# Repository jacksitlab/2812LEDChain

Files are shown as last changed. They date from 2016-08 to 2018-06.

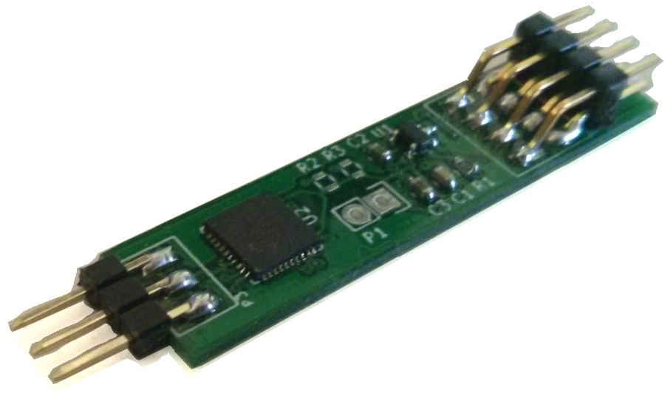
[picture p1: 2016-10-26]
platine.jpg

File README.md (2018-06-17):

## 2812LEDChain

This Project is based on a little piece of Hardware I build for accessing 2812LEDs via I2C-Bus(aka TWI). In my special case I use a Raspberry PI to control them.
The Clou: It is possible to wire them from board to board and control them seperately. So you can wire the seperated LEDChains from one to another.
The Controller works like a simple 32bit adressable I2C-EEPROM where you can write the RGB-Values.

## Why the extra board? There is already a lib for the raspi that can control 2812LEDs.

Yeah, thats right. But this lib is using the PWM-output Pin and many of my Projects are using this as it should be. That's why I want to put it on a place where I can control them with a seperate address.
 
## Folders

* pcb: all KiCAD files (Schematics and Layout files)
* firmware: all microcontroller files for CodeComposerStudio(from Texas Instruments)
* raspberry: all files to remote control the LEDChain from a Raspberry PI with python

## Installation / Usage

### Firmware installation

* File > Import > Code Composer Studio > CCS Projects
* Select Directory and Finish
* Debug with a programmer (a launchpad also works) with connected TEST and RESET Pin. Don't forget GND.

### For Raspberry PI with Python

* copy ws2812ledchain.py to your python project folder
* use it from a seperate file like this below.

```
	
	from ws2812ledchain import *

	chain=WS2812Chain(1)  //1 =>bus number(i2c-1 on raspi 2 and 3, i2c-0 on raspi 1)
	leds=chain.Add(0x44,256)  //0x44 => 7bit address of the chain element. 0x44 is the default. can be modified in firmware, 256 leds to handle
	leds.Test()
	leds.RingBuffer(500,0)  //shift forward every LED every 500ms 
	time.sleep(5)
	leds.RingBuffer(100,1)  //shift backward every LED every 100ms

```

### For Raspberry PI with Web-API

* install apache webserver

```

	pi@raspberrypi ~ $ sudo apt-get install apache2

```

* copy ws2812ledchain.py and api.py to /usr/lib/cgi-bin/
* change userrights for those files

```

	pi@raspberrypi ~ $ sudo chmod 0755 /usr/lib/cgi-bin/*.py

```

* add cgi support in your apache config file

```

	<Directory "/usr/lib/cgi-bin">
		AllowOverride None
		Options +ExecCGI -MultiViews +SymLinksIfOwnerMatch
		Order allow,deny
		Allow from all
	</Directory>

```

* maybe you have to enable cgi mod for apache

```

	sudo a2enmod cgi
	sudo /etc/init.d/apache2 restart
```

* make a simple get request with javascript from your page (here with jQuery)

```

	$.ajax({
		url:'cgi-bin/api.py?task='+task,
		success: function(r){
			console.log(r);
		}
    });

```

## TODO

* Set RGBChain Length via Command
* Change I2C-Address via Command
* Add more functions ...

## License

Beerware License.

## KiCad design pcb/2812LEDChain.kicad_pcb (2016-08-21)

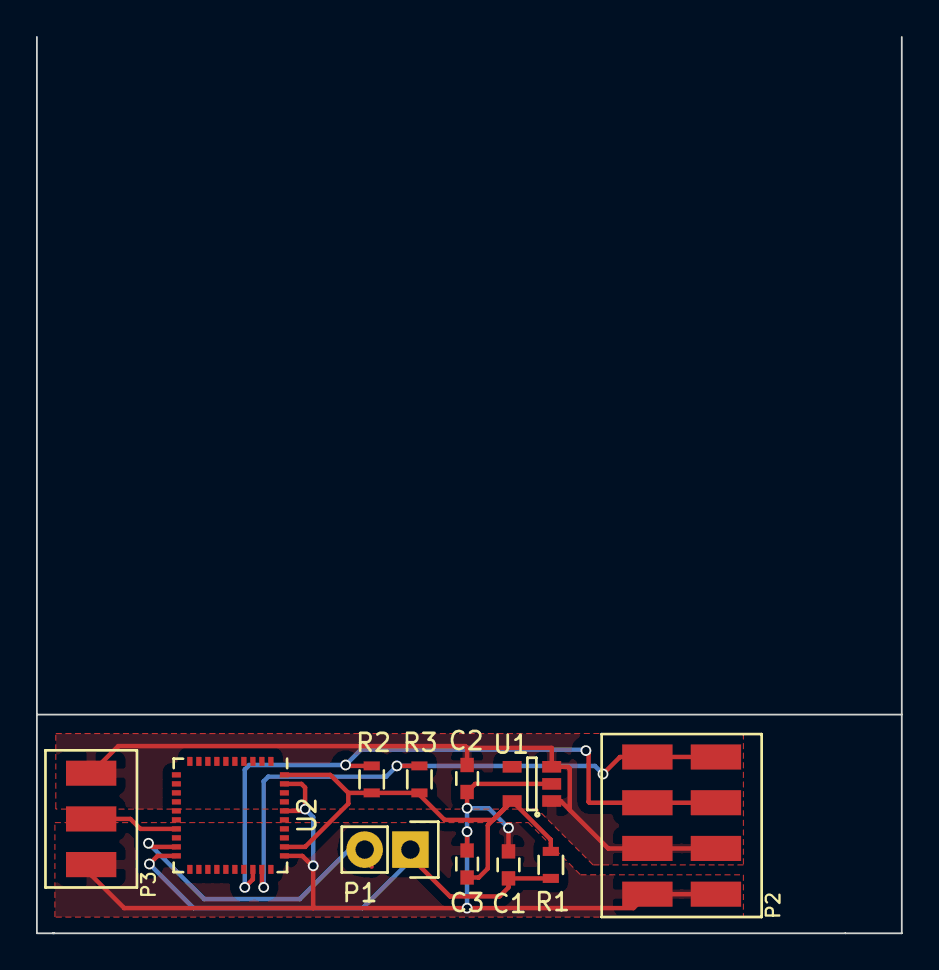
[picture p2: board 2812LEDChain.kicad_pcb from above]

Board: 2 copper layers, 48.1 x 49.8 mm, 11 parts (0 on the bottom side), 8 nets.

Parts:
C1: 1n; C_0603
C2, C3: 1u; C_0603
P1: CONN_01X02; Pin_Header_Straight_1x02
P2: CONN_02X04; PINHEAD1-8_SMD
P3: CONN_01X03; PINHEAD1-3_SMD
R1: 47k; R_0603
R2, R3: 10k; R_0603
U1: LD59015; SOT-23-5
U2: MSP430F5739; QFN-40-1EP_6x6mm_Pitch0.5mm

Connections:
+3V3: C3.1, R1.1, R2.1, R3.1, U1.5, U2.32, U2.40
+5V: C2.1, P2.5, P2.6, P3.1, U1.1, U1.3
/DO: P3.2, U2.17
/RST: C1.1, P1.1, R1.2, U2.20
/SCL: P2.1, P2.2, R3.2, U2.29
/SDA: P2.3, P2.4, R2.2, U2.28
/TEST: P1.2, U2.19
GND: C1.2, C2.2, C3.2, P2.7, P2.8, P3.3, U1.2, U2.31, U2.36, U2.39

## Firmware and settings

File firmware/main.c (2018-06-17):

/**
 * |==================================|
 * |                                  |
 * |           Memory 1               |
 * |          for RGB Values          |
 * |        Size: NUMLEDSMAX          |
 * |             (FRAM)               |
 * |==================================|
 *
 *
 * |==================================|
 * |                                  |
 * |           Memory 2               |
 * |        for DMA output            |
 * |  Size: 3* RGBMem + ResetOffset   |
 * |           (FRAM)                 |
 * |==================================|
 *
 *
 * |==================================|
 * |                                  |
 * |           Memory 3               |
 * |          for Config              |
 * |            (InfoB)               |
 * |==================================|
 *
 */



#include <msp430.h> 

#include "i2c.h"
#include "spi.h"
#include "constants.h"

#ifdef COMPILE_MINIMAL
#else
#include "demos.h"
#define PROGRAM_IDLE 0
#define PROGRAM_RECALCRGB 1
#define PROGRAM_OFFSET 2
#define PROGRAM_KITT 3
#define PROGRAM_RINGBUFFER 4
#define PROGRAM_FADEOUT 5
#define PROGRAM_FADEIN 6
#define PROGRAM_FADEOUT_LTR 7
#define PROGRAM_FADEIN_LTR 8
#define PROGRAM_FADEOUT_RTL 9
#define PROGRAM_FADEIN_RTL 10


unsigned int programMode=PROGRAM_IDLE;
static unsigned int timercounter=0;
#endif

void clock_init(void)
{
	 CSCTL0_H = 0xA5;
	  CSCTL1 |= DCORSEL + DCOFSEL0 + DCOFSEL1;   // Set max. DCO setting
	  CSCTL2 = SELA_3 + SELS_3 + SELM_3;        // set ACLK = MCLK = DCO
	  CSCTL3 = DIVA__32 + DIVS_0 + DIVM_0;        // set all dividers to 0

	  __delay_cycles(76563);
}
void i2c_onwritecomplete(unsigned char* ptr,unsigned int len)
{
	//spi_calculate(rgbmem,rgb_getnumleds());
	//spi_dma_write();
#ifdef COMPILE_MINIMAL
	spi_calculate(rgbmem,rgb_getlength());
    spi_dma_write();
#else
	programMode=PROGRAM_RECALCRGB;
#endif
}
unsigned int ringbufferreset=1000;
unsigned int fadetimerreset=1000;
unsigned int fadedirection_index=0;
void i2c_oncommand(unsigned int command,unsigned char* params)
{
#ifndef COMPILE_MINIMAL
	switch(command)
	{
		case COMMAND_OFFSET:
		{
			programMode=PROGRAM_OFFSET;
			parammem[0]=*params++;
			break;
		}
		case COMMAND_DEMO_KITT:
		{
			programMode=PROGRAM_KITT;
			timercounter=demo_getKITTCounterInit(rgb_getlength(),10);
			break;
		}
		case COMMAND_RINGBUFFER:
		{
			programMode=PROGRAM_RINGBUFFER;
			parammem[0]=*params++;
			parammem[1]=*params++;
			break;
		}
		case COMMAND_SETLENGTH:
		{
			unsigned int len=*params++;
			len<<=8;
			len+=*params;
			if(len>0 && len<NUMLEDSMAX)
				rgb_setlength(len);
			break;
		}
		case COMMAND_SETADDRESS:
		{
			break;
		}
		case COMMAND_SETFACTORS:
		{

			break;
		}
		case COMMAND_FADEOUT:
		case COMMAND_FADEIN:
		{
			parammem[0]=*params++;
			parammem[1]=*params++;
			programMode=command==COMMAND_FADEOUT?PROGRAM_FADEOUT:PROGRAM_FADEIN;
			break;
		}
		case COMMAND_FADEIN_LTR:
		case COMMAND_FADEOUT_LTR:
		{
			parammem[0]=*params++;
			parammem[1]=*params++;
			fadedirection_index=0;
			programMode=command==COMMAND_FADEOUT_LTR?PROGRAM_FADEOUT_LTR:PROGRAM_FADEIN_LTR;
			break;
		}
		case COMMAND_FADEIN_RTL:
		case COMMAND_FADEOUT_RTL:
		{
			parammem[0]=*params++;
			parammem[1]=*params++;
			fadedirection_index=rgb_getnumleds();
			programMode=command==COMMAND_FADEOUT_RTL?PROGRAM_FADEOUT_RTL:PROGRAM_FADEIN_RTL;
			break;
		}
		default:
			break;
	}
#endif
}
/*
 * main.c
 */

void main(void) {
    WDTCTL = WDTPW | WDTHOLD;	// Stop watchdog timer
	
    clock_init();
    i2c_init();
    spi_init();
    rgb_initdemo();

//    spi_calculate(rgbmem,rgb_getlength());

//    spi_dma_write();


    //=====TimerB Init for (24MHz)  / 24000 = 1000Hz = 1ms

    TB0CCTL0 = CCIE;                          // TACCR0 interrupt enabled
    TB0CCR0 = 24000;
    TB0CTL = TBSSEL__SMCLK + MC__UP + ID__1;                 // SMCLK, UP mode

    __bis_SR_register(GIE);        // Enter LPM0 w/ interrupts
    programMode=PROGRAM_RECALCRGB;
    while(1)
    {

#ifndef COMPILE_MINIMAL
    	switch(programMode)
    	{
    		case PROGRAM_RECALCRGB:
    		{
    			 spi_calculate(rgbmem,rgb_getnumleds());
    			 spi_dma_write();
    			 programMode=PROGRAM_IDLE;
    			 break;
    		}
    		case PROGRAM_OFFSET:
    		{	signed char x=(parammem[0]);
    			rgb_addoffset(x);
    			programMode=PROGRAM_RECALCRGB;
    			break;
    		}
    		case PROGRAM_RINGBUFFER:
    		{
    			ringbufferreset=parammem[0];
    			ringbufferreset<<=8;
    			ringbufferreset|=parammem[1];
    			timercounter=ringbufferreset;
    			while(timercounter>0)_nop();
    			rgb_shift(parammem[2]);
    			spi_calculate(rgbmem,rgb_getnumleds());
    			spi_dma_write();
    			break;
    		}
    		case PROGRAM_KITT:
    		{


    			programMode=PROGRAM_IDLE;
    			break;
    		}
    		case PROGRAM_FADEOUT:
    		case PROGRAM_FADEIN:
    		{
    			fadetimerreset=parammem[0];
    			fadetimerreset<<=8;
    			fadetimerreset|=parammem[1];
    			timercounter=fadetimerreset;
    			if(programMode==PROGRAM_FADEOUT)
    				rgb_decrement_factors();
    			else
    				rgb_increment_factors();
    			while(timercounter>0)_nop();
    			spi_calculate(rgbmem,rgb_getnumleds());
    			spi_dma_write();
    			if(programMode==PROGRAM_FADEOUT)
    			{
    				if(rgb_getfactor(0)<=0)
    					programMode=PROGRAM_IDLE;
    			}
    			else
    			{
    				if(rgb_getfactor(0)>=1)
    				    programMode=PROGRAM_IDLE;
    			}
    			break;
    		}
    		case PROGRAM_FADEOUT_LTR:
    		case PROGRAM_FADEIN_LTR:
    		{
    			fadetimerreset=parammem[0];
    		    fadetimerreset<<=8;
    		    fadetimerreset|=parammem[1];
    		    timercounter=fadetimerreset;
    		    if(programMode==PROGRAM_FADEOUT_LTR)
    		        rgb_decrement_factors_left(fadedirection_index);
    		    else //PROGRAM_FADEIN_LTR
    		    	rgb_increment_factors_left(fadedirection_index);
    		    while(timercounter>0)_nop();
    		    spi_calculate(rgbmem,rgb_getnumleds());
    		    spi_dma_write();
    		    if(programMode==PROGRAM_FADEOUT_LTR)
    		    {
    		    	if(rgb_getfactor(fadedirection_index)<0.5)
    		  	    	if(fadedirection_index<rgb_getnumleds()-1)
    		  	    		fadedirection_index++;
					if(rgb_getfactor(rgb_getnumleds()-1)<=0)
						programMode=PROGRAM_IDLE;
    		    }
    		    else	//PROGRAM_FADEIN_LTR
    		    {
    		    	if(rgb_getfactor(fadedirection_index)>0.5)
    		  	    	if(fadedirection_index<rgb_getnumleds()-1)
    		  	    		fadedirection_index++;
					if(rgb_getfactor(rgb_getnumleds()-1)>=1)
						programMode=PROGRAM_IDLE;
    		    }
    		    break;
    		}
    		default:
    		{
    			//programMode=PROGRAM_IDLE;
    			_nop();
    			break;
    		}
    	}
#endif
    }
}
#ifndef COMPILE_MINIMAL
// Timer B0 interrupt service routine
#if defined(__TI_COMPILER_VERSION__) || defined(__IAR_SYSTEMS_ICC__)
#pragma vector = TIMER0_B0_VECTOR
__interrupt void Timer_B (void)
#elif defined(__GNUC__)
void __attribute__ ((interrupt(TIMER0_B0_VECTOR))) Timer_B (void)
#else
#error Compiler not supported!
#endif
{
//	spi_dma_write();

	if(timercounter>0)
	{
		timercounter--;
	}
	else
	{
	//	timercounter=5000;
//		programMode=PROGRAM_RECALCRGB;

	}
	//spi_calculate(rgbmem,rgb_getnumleds());
	//spi_dma_write();
}

#endif

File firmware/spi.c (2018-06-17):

/*
 * spi.c
 *
 *  Created on: 08.08.2016
 *      Author: Jack
 */
#include <msp430.h>
#include "constants.h"
#include "i2c.h"

#define RESET_OFFSET 40
#define RGBFACTOR_INCDEC 0.05f

#pragma location=0xE400
unsigned char ledoutputmem[3*3*NUMLEDSMAX+RESET_OFFSET];
#pragma SET_DATA_SECTION(".fram_data_noinit")
float rgb_factors[NUMLEDSMAX];
static unsigned char incdecIndex=0;
const float incdecFactors[]={
		0.05f,0.1f,0.15f,0.2f,0.25f,0.3f,0.35f,0.4f,0.45f,0.5f,
		0.55f,0.6f,0.65f,0.7f,0.75f,0.8f,0.85f,0.9f,0.95f,1.0f
};

//unsigned char ledoutfactors[NUMLEDSMAX+1/2];//4bit factor 0=>shift right 0; 0x0F
#pragma SET_DATA_SECTION()

const unsigned long convert_table_3bit [256] = {		// 1 Byte => 3 Byte
 0x924924,0x924926,0x924934,0x924936,0x9249A4,0x9249A6,0x9249B4,0x9249B6, // 0 ... 7
 0x924D24,0x924D26,0x924D34,0x924D36,0x924DA4,0x924DA6,0x924DB4,0x924DB6, // 8 ... 15
 0x926924,0x926926,0x926934,0x926936,0x9269A4,0x9269A6,0x9269B4,0x9269B6,
 0x926D24,0x926D26,0x926D34,0x926D36,0x926DA4,0x926DA6,0x926DB4,0x926DB6,
 0x934924,0x934926,0x934934,0x934936,0x9349A4,0x9349A6,0x9349B4,0x9349B6,
 0x934D24,0x934D26,0x934D34,0x934D36,0x934DA4,0x934DA6,0x934DB4,0x934DB6,
 0x936924,0x936926,0x936934,0x936936,0x9369A4,0x9369A6,0x9369B4,0x9369B6,
 0x936D24,0x936D26,0x936D34,0x936D36,0x936DA4,0x936DA6,0x936DB4,0x936DB6,
 0x9A4924,0x9A4926,0x9A4934,0x9A4936,0x9A49A4,0x9A49A6,0x9A49B4,0x9A49B6,
 0x9A4D24,0x9A4D26,0x9A4D34,0x9A4D36,0x9A4DA4,0x9A4DA6,0x9A4DB4,0x9A4DB6,
 0x9A6924,0x9A6926,0x9A6934,0x9A6936,0x9A69A4,0x9A69A6,0x9A69B4,0x9A69B6,
 0x9A6D24,0x9A6D26,0x9A6D34,0x9A6D36,0x9A6DA4,0x9A6DA6,0x9A6DB4,0x9A6DB6,
 0x9B4924,0x9B4926,0x9B4934,0x9B4936,0x9B49A4,0x9B49A6,0x9B49B4,0x9B49B6,
 0x9B4D24,0x9B4D26,0x9B4D34,0x9B4D36,0x9B4DA4,0x9B4DA6,0x9B4DB4,0x9B4DB6,
 0x9B6924,0x9B6926,0x9B6934,0x9B6936,0x9B69A4,0x9B69A6,0x9B69B4,0x9B69B6,
 0x9B6D24,0x9B6D26,0x9B6D34,0x9B6D36,0x9B6DA4,0x9B6DA6,0x9B6DB4,0x9B6DB6,
 0xD24924,0xD24926,0xD24934,0xD24936,0xD249A4,0xD249A6,0xD249B4,0xD249B6,
 0xD24D24,0xD24D26,0xD24D34,0xD24D36,0xD24DA4,0xD24DA6,0xD24DB4,0xD24DB6,
 0xD26924,0xD26926,0xD26934,0xD26936,0xD269A4,0xD269A6,0xD269B4,0xD269B6,
 0xD26D24,0xD26D26,0xD26D34,0xD26D36,0xD26DA4,0xD26DA6,0xD26DB4,0xD26DB6,
 0xD34924,0xD34926,0xD34934,0xD34936,0xD349A4,0xD349A6,0xD349B4,0xD349B6,
 0xD34D24,0xD34D26,0xD34D34,0xD34D36,0xD34DA4,0xD34DA6,0xD34DB4,0xD34DB6,
 0xD36924,0xD36926,0xD36934,0xD36936,0xD369A4,0xD369A6,0xD369B4,0xD369B6,
 0xD36D24,0xD36D26,0xD36D34,0xD36D36,0xD36DA4,0xD36DA6,0xD36DB4,0xD36DB6,
 0xDA4924,0xDA4926,0xDA4934,0xDA4936,0xDA49A4,0xDA49A6,0xDA49B4,0xDA49B6,
 0xDA4D24,0xDA4D26,0xDA4D34,0xDA4D36,0xDA4DA4,0xDA4DA6,0xDA4DB4,0xDA4DB6,
 0xDA6924,0xDA6926,0xDA6934,0xDA6936,0xDA69A4,0xDA69A6,0xDA69B4,0xDA69B6,
 0xDA6D24,0xDA6D26,0xDA6D34,0xDA6D36,0xDA6DA4,0xDA6DA6,0xDA6DB4,0xDA6DB6,
 0xDB4924,0xDB4926,0xDB4934,0xDB4936,0xDB49A4,0xDB49A6,0xDB49B4,0xDB49B6,
 0xDB4D24,0xDB4D26,0xDB4D34,0xDB4D36,0xDB4DA4,0xDB4DA6,0xDB4DB4,0xDB4DB6,
 0xDB6924,0xDB6926,0xDB6934,0xDB6936,0xDB69A4,0xDB69A6,0xDB69B4,0xDB69B6,
 0xDB6D24,0xDB6D26,0xDB6D34,0xDB6D36,0xDB6DA4,0xDB6DA6,0xDB6DB4,0xDB6DB6   // ... 255
};
float rgb_getfactor(unsigned int index)
{
	return rgb_factors[index];
}
void rgb_increment_factors(void)
{
	unsigned int i;
	incdecIndex++;
	if(incdecIndex>=sizeof(incdecFactors))
		incdecIndex=sizeof(incdecFactors)-1;
	float v=incdecFactors[incdecIndex];
	for(i=0;i<NUMLEDSMAX;i++)
		rgb_factors[i]=v;
}
void rgb_decrement_factors(void)
{
	unsigned int i;
	if(incdecIndex>0)
		incdecIndex--;
	float v=incdecFactors[incdecIndex];
	for(i=0;i<NUMLEDSMAX;i++)
		rgb_factors[i]=v;
}
void rgb_decrement_factors_left(unsigned int toleft)
{
	float v;
	do
	{
		v=rgb_factors[toleft];
		v-=RGBFACTOR_INCDEC;
		if(v<0)
			v=0;
		rgb_factors[toleft]=v;
	}while(toleft--);
}
void rgb_decrement_factors_right(unsigned int toright)
{
	float v;
	do
	{
		v=rgb_factors[toright];
		v-=RGBFACTOR_INCDEC;
		if(v<0)
			v=0;
		rgb_factors[toright]=v;
	}while(toright++<rgb_numleds-1);
}
void rgb_increment_factors_left(unsigned int toleft)
{
	float v;
	do
	{
		v=rgb_factors[toleft];
		v+=RGBFACTOR_INCDEC;
		if(v>1)
			v=1;
		rgb_factors[toleft]=v;
	}while(toleft--);
}
void rgb_increment_factors_right(unsigned int toright)
{
	float v;
	do
	{
		v=rgb_factors[toright];
		v+=RGBFACTOR_INCDEC;
		if(v>1)
			v=1;
		rgb_factors[toright]=v;
	}while(toright++<rgb_numleds-1);
}
void calc_RGB_3bit (unsigned char R, unsigned char G, unsigned char B,unsigned char n)
{
	R=(unsigned char)((float)R*rgb_factors[n]);
	G=(unsigned char)((float)G*rgb_factors[n]);
	B=(unsigned char)((float)B*rgb_factors[n]);

	unsigned char *ptr=&ledoutputmem[RESET_OFFSET+(9*n)];
	// Gruen
	*ptr++= (unsigned char)(convert_table_3bit[G]>>16);
	*ptr++= (unsigned char)(convert_table_3bit[G]>>8);
	*ptr++= (unsigned char)(convert_table_3bit[G]);
	// Rot
	*ptr++= (unsigned char)(convert_table_3bit[R]>>16);
	*ptr++=(unsigned char)(convert_table_3bit[R]>>8);
	*ptr++= (unsigned char)(convert_table_3bit[R]);
	// Blau
	*ptr++= (unsigned char)(convert_table_3bit[B]>>16);
	*ptr++= (unsigned char)(convert_table_3bit[B]>>8);
	*ptr++= (unsigned char)(convert_table_3bit[B]);
}

void spi_init(void)
{
	  P2SEL1 |= BIT5;
	  UCA1CTLW0 |= UCSWRST;                     // **Put state machine in reset**
	  UCA1CTLW0 |= UCMST+UCSYNC+UCCKPL+UCMSB;   // 3-pin, 8-bit SPI master
	                                            // Clock polarity high, MSB
	  UCA1CTLW0 |= UCSSEL__SMCLK;                    // SMCLK
	  UCA1BR0 = 0x09;                          //  fsystem/10 = 2.400MHz
	  UCA1BR1 = 0;                              //
	  UCA1MCTLW = 0;                            // No modulation
	  UCA1CTLW0 &= ~UCSWRST;                    // **Initialize USCI state machine**

	  __data16_write_addr((unsigned short) &DMA0SA,(unsigned long)&ledoutputmem[1]);
	                                            // Source block address
	  __data16_write_addr((unsigned short) &DMA0DA,(unsigned long)&UCA1TXBUF);
	   // channel 17 = UCATXIFG as trigger for DMA
	    DMACTL0 = DMA0TSEL__UCA1TXIFG;
	    DMACTL1 = 0;
	    DMACTL2 = 0;
	    DMACTL3 = 0;                                // Destination single address
	  DMA0SZ = sizeof(ledoutputmem)-1  ;                          // Block size
	  DMA0CTL = DMASRCINCR_3 + DMASBDB + DMALEVEL+ DMADT_0;		// inc src_adr, byte=>byte, level sensitive, Repeated single
	  DMA0CTL |= DMAEN;                         // Enable DMA0

	  //clear first bytes of outputmem for led reset signal
	  unsigned int i=RESET_OFFSET;
	  unsigned char* ptr=ledoutputmem;
	  while(i--)
		  *ptr++=0;

	  for(i=0;i<NUMLEDSMAX;i++)
		rgb_factors[i]=1.0f;
}
/*
 * Calculate rgbValues to dma-RAW-bytes for DMA sending
 *
 * inputs: *src = Pointer of rgb-values
 * 			len = number of rgb-values (for 6LEDS = 6, not 18)
 *
 */
void spi_calculate(unsigned char* src,unsigned int len)
{
	unsigned char i=0;
	while(len--)
	{
		calc_RGB_3bit(*(src+0),*(src+1),*(src+2),i++);
		src+=3;
	}


}
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
